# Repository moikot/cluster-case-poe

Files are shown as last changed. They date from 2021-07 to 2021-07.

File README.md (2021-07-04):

# A quiet case for three Raspberry Pis

* ✨Power over Ethernet
* ✨Hot-swap support 
* ✨PWM fans support
---

## Table of Contents

- [Enclosure](#enclosure)
  - [Power and I2C rail](#power-and-i2c-rail)
  - [Fan controller](#fan-controller)
  - [Bill of materials](#enclosure-bill-of-materials)
- [Frames](#frames)
  - [PoE assembly](#poe-assembly)
  - [Bill of materials](#frames-bill-of-materials)
- [Other hardware needed](#other-hardware-needed)
- [License](#license)

## Enclosure
<p align="center">
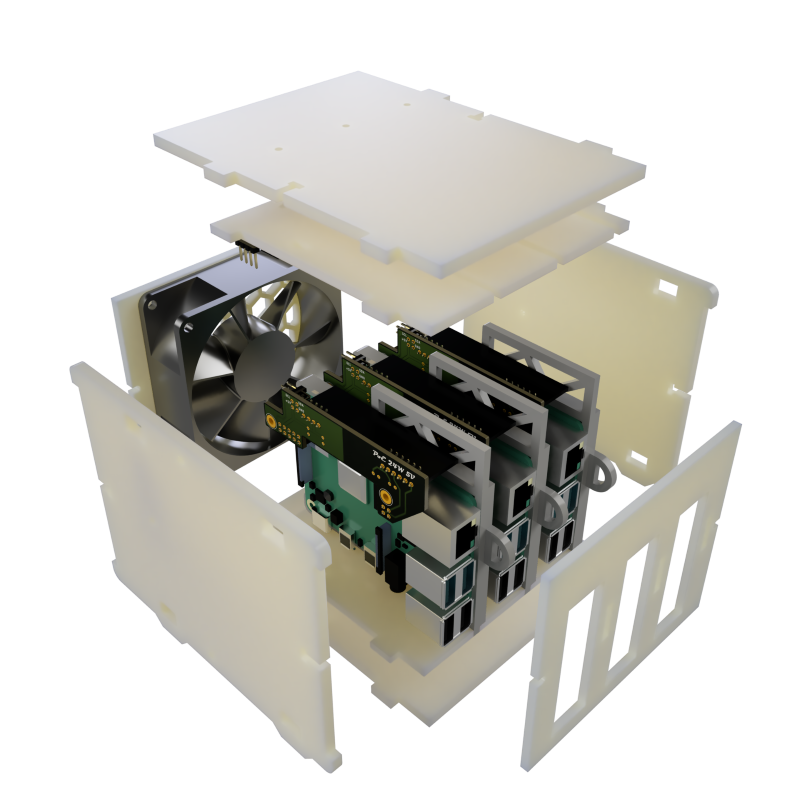
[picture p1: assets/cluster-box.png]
Enclosure

</p>

The case box is built from the following parts ([drawings](drawings/cluster-box-drawings.pdf)):

* Left, right, top, and bottom panels.
* Top and bottom panels with grooves for the Raspberry Pi frames.
* A back panel with a fan grill for 80mm x 80mm fan.
* A front panel with openings for USB and Ethernet ports. 

> Watch this [video](https://youtu.be/zfYN2NjLpm8) to see how to assembly the case.

### Power and I2C rail

The power and I2C rail connects all Raspberry Pis to the I2C bus and provides power to the fan controller and a chassis fan. Low forward drop Schottky diodes combined in an OR-ing circuit provide power to the load when at least one Raspberry Pi is installed without the risk of reverse current flow. 

<p align="center">
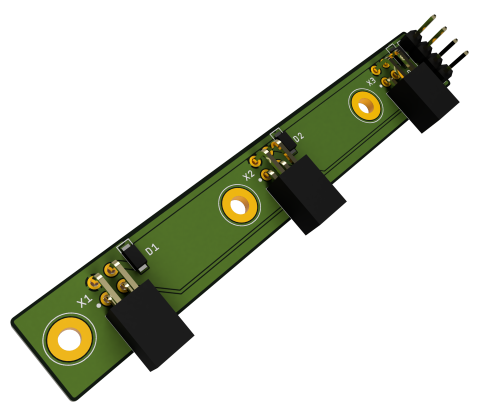
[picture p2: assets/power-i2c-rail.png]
Power I2C rail

</p>

> * [Schematics and PCB (EagleCAD)](power-rail)
> * [BOM](power-rail/power-rail-bom.csv)

### Fan controller

The fan controller converts 5V to 12V and uses [EMC2101-R IC](https://www.microchip.com/wwwproducts/en/EMC2101) from Microchip/SMSC to control a 4-pin PWM fan and monitor its speed via the I2C bus. This controller is installed on the left panel of the enclosure and connected to the [Power and I2C rail](#power-and-i2c-rail).

<p align="center">
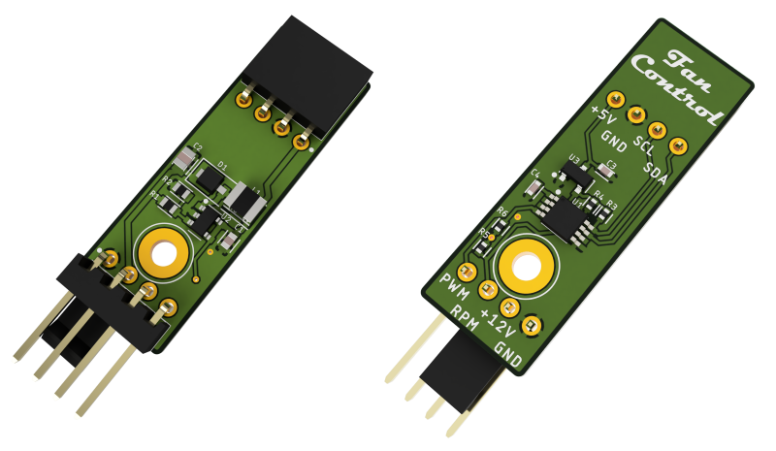
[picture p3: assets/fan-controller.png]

</p>

> * [Schematics and PCB (EagleCAD)](fan-controller)
> * [BOM](fan-controller/fan-controller-bom.csv)

### Bill of materials

| Part | Quantity | Link |
|---|---|---|
| M2.5 x 14mm screw | 3 | [M2.5 machine screws nuts kit](https://www.ebay.com/itm/182282169506) |
| M2.5 x 10mm screw | 1 | [M2.5 machine screws nuts kit](https://www.ebay.com/itm/182282169506) |
| M2.5 nut | 4 | [M2.5 machine screws nuts kit](https://www.ebay.com/itm/182282169506) |
| M2.5 x 2mm spacer | 4 | [M2.5 round plastic spacer](https://www.digikey.com/en/products/detail/w%C3%BCrth-elektronik/960020021/9488359) |
| M3 x 12mm screw | 8 | 	[M3x12mm machine screws](https://www.amazon.com/Uxcell-a15070200ux0058-Stainless-Phillips-Screws/dp/B012TE1TBS) |
| M3 nut | 8 | [M3 hexagon nuts](https://www.amazon.com/uxcell-Metric-Stainless-Hexagon-Silver/dp/B07H3T4859) |
| M3 nylon washer | 8 | [M3 nylon flat washers](https://www.amazon.com/uxcell-Insulation-Spacer-Washer-Gasket/dp/B016EPLM5G) |
| M4 x 14mm screw | 4 | [M4x14mm machine screws](https://www.amazon.com/uxcell-M4x14mm-Phillips-Stainless-Fasteners/dp/B07MF44LGC) |
| M4 nut | 4 | [M4 hexagon nuts](https://www.amazon.com/uxcell-Metric-Stainless-Hexagon-Silver/dp/B07H3VF3BF) |
| 80mm x 80mm x 25mm fan | 1 | [Noctua NF-A8 PWM](https://noctua.at/en/nf-a8-pwm) |
| Power and I2C rail | 1 | [Schematics and PCB (EagleCAD)](power-rail), [BOM](power-rail/power-rail-bom.csv) |
| Fan controller | 1 | [Schematics and PCB (EagleCAD)](fan-controller), [BOM](fan-controller/fan-controller-bom.csv) |
| Case panels | 8 | [Drawings](drawings/cluster-box-drawings.pdf), [Templates for laser cutting](drawings/cluster-box-laser-cut.pdf) |

## Frames

Raspberry Pis need to be mounted on frames so that they can be pushed into the case and retracted individually ([drawings](drawings/frame-drawings.pdf)).

<p align="center">
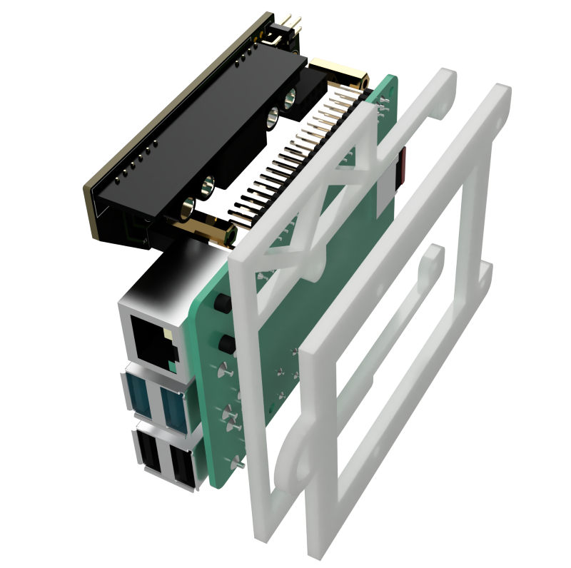
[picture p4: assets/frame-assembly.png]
Frame assembly

</p>

### PoE assembly

The solution relies on a custom PoE HAT with [RT5400-5V 30W module](https://www.aliexpress.com/item/33038562052.html). For this HAT to work, the switch your cluster is connected to needs to support IEEE 802.3af Power over Ethernet protocol (e.g. [TL-SG1005P switch](https://www.tp-link.com/us/business-networking/poe-switch/tl-sg1005p/)). 

<p align="center">
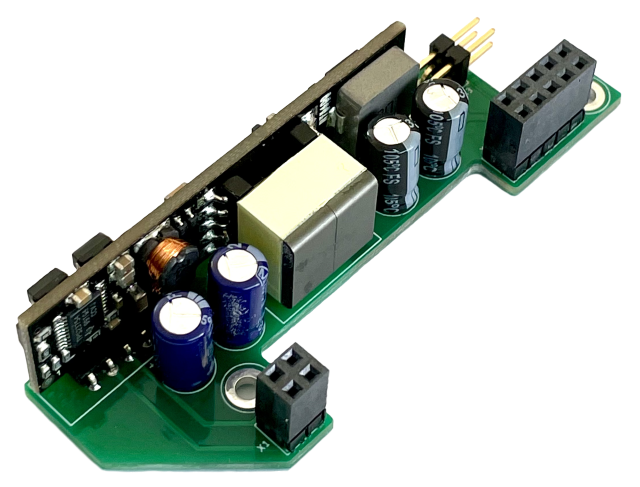
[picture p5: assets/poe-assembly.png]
Frame assembly

</p>

> * [Schematics and PCB (EagleCAD)](poe-assembly)
> * [BOM](poe-assembly/poe-assembly-bom.csv)

### Bill of materials
| Part | Quantity | Link |
|---|---|---|
| M2.5 x 10mm screw | 12 | [M2.5 machine screws nuts kit](https://www.ebay.com/itm/182282169506) |
| M2.5 x 5mm screw | 6 | [M2.5 machine screws nuts kit](https://www.ebay.com/itm/182282169506) |
| M2.5 nut | 6 | [M2.5 machine screws nuts kit](https://www.ebay.com/itm/182282169506) |
| M2.5 x 14mm F/F hex brass standoff | 6 | [Hex standoff M2.5 x 14mm brass](https://www.digikey.com/en/products/detail/harwin-inc/R25-1001402/3924434) |
| Raspberry Pi 4 Model B 4-8Gb | 3 | [Raspberry Pi 4](https://www.amazon.com/Uxcell-a15070200ux0058-Stainless-Phillips-Screws/dp/B012TE1TBS) | 
| Micro SD 32 Gb | 3 | [SanDisk Ultra 32GB](https://www.amazon.com/SanDisk-Ultra-UHS-I-Memory-Adapter/dp/B00M55C0NS) |
| PoE assembly | 3 | [Schematics and PCB (EagleCAD)](poe-assembly), [BOM](poe-assembly/poe-assembly-bom.csv) |
| Frame panels | 2 x 3 | [Drawings](drawings/frame-drawings.pdf), [Templates for laser cutting](drawings/frame-laser-cut.pdf) |

## Other hardware needed

* Three Ethernet patch cables 230-250mm length.
* A switch with 802.3af Power over Ethernet support (e.g. [TL-SG1005P switch](https://www.tp-link.com/us/business-networking/poe-switch/tl-sg1005p/)).

## License
This work is licensed under a Creative Commons Attribution-ShareAlike 4.0 International License, check [LICENSE](LICENSE) for more information.

You can support my work in the field of open-source hardware by clicking .

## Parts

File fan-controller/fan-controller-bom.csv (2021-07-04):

Designator | Name | Value | Amount | Case | Link
X1 | Connector | SSW-104-02-G-S-RA | 1 |  | https://no.mouser.com/ProductDetail/SSW-104-02-G-S-RA
X2 | Connector | KF2510-AW 3+1P | 1 |  | https://www.aliexpress.com/item/32961935772.html
C1 | Capacitor | 2.2uF 10V | 1 | 0603 | https://no.mouser.com/ProductDetail/187-CL10A225KP8NNNC
C2 | Capacitor | 10uF 16V | 1 | 0805 | https://no.mouser.com/ProductDetail/187-CL21A106KOQNNNE
C3,C4 | Capacitor | 0.1uF 10V | 2 | 0402_L | https://no.mouser.com/ProductDetail/187-CL05A104KP5NNWC
L1 | Inductor | 10uH | 1 | 1210 | https://no.mouser.com/ProductDetail/963-CBC3225T100KR
D1 | Schottky Diode |  | 1 | DO-216AA | https://no.mouser.com/ProductDetail/863-MBRM140T1G
R1 | Resistor | 43.2K | 1 | 0603 | https://no.mouser.com/ProductDetail/603-RC0603FR-0743K2L
R2 | Resistor | 4.99K | 1 | 0603 | https://no.mouser.com/ProductDetail/603-RC0603FR-074K99L
R3,R4,R6 | Resistor | 10K | 3 | 0402 | https://no.mouser.com/ProductDetail/603-RC0402FR-0710KL
R5 | Resistor | 5.6K | 1 | 0402 | https://no.mouser.com/ProductDetail/603-AC0402FR-075K6L
U1 | Voltage regulator | MIC2288YD5-TR | 1 | SOT-23-5 | https://no.mouser.com/ProductDetail/998-MIC2288YD5TR
U2 | Fan controller | EMC2101-R-ACZL-TR | 1 | MSOP-8 | https://no.mouser.com/ProductDetail/886-EMC2101RACZLTR
U3 | LDO 3.3V | AP7313-33SRG-7 | 1 | SOT-23-3 | https://no.mouser.com/ProductDetail/621-AP7313-33SRG-7

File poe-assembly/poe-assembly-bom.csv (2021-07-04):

Designator | Name | Value | Amount | Case | Link
X1 | Connector | ESQ-102-12-G-D | 1 |  | https://no.mouser.com/ProductDetail/200-ESQ10212GD
X2 | Connector | ESQ-105-12-G-D | 1 |  | https://no.mouser.com/ProductDetail/200-ESQ10512GD
X3 | Connector | TSW-102-08-G-D-RA | 1 |  | https://no.mouser.com/ProductDetail/TSW-102-08-G-D-RA
C1,C2 | Capacitor | 22uF 100V | 2 |  | https://no.mouser.com/ProductDetail/667-ECA-2AM220I
C3,C4 | Capacitor | 330uF 10V | 2 |  | https://no.mouser.com/ProductDetail/667-EEU-FS1A331
RT5400 | PoE module | RT5400 5V | 1 |  | https://www.aliexpress.com/item/33038562052.html

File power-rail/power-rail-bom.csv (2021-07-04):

Designator | Name | Value | Amount | Case | Link
X1,X2,X3 | Connector | SSW-102-02-G-D-RA | 3 |  | https://no.mouser.com/ProductDetail/SSW-102-02-G-D-RA
X4 | Connector | TSW-104-07-F-S | 1 |  | https://no.mouser.com/ProductDetail/200-TSW10407FS
D1,D2,D2 | Schottky Diode | RB161MM-20TR | 3 |  | https://no.mouser.com/ProductDetail/755-RB161MM-20TR

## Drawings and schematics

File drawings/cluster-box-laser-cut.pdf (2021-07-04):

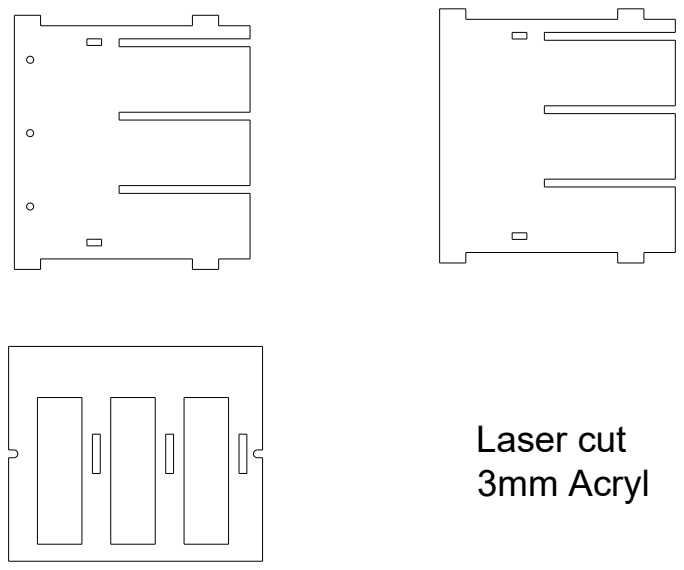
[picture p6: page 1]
Laser cut 3mm Acryl

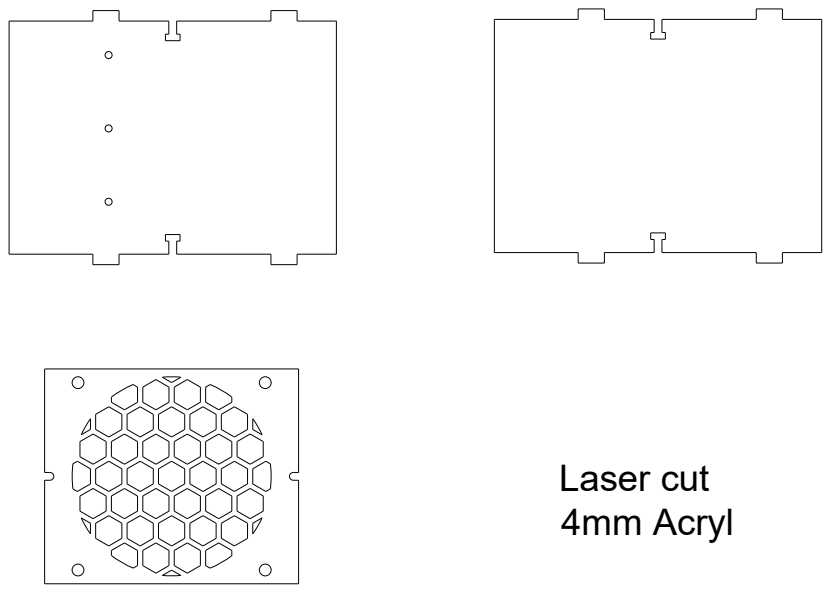
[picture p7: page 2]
Laser cut 4mm Acryl

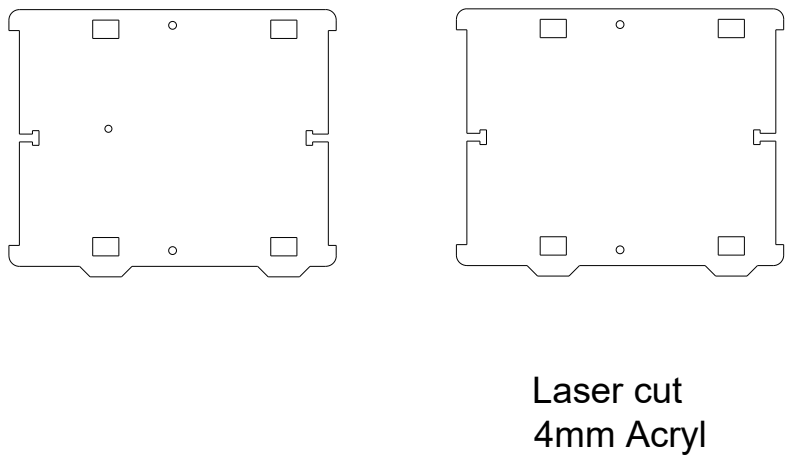
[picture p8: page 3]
Laser cut 4mm Acryl

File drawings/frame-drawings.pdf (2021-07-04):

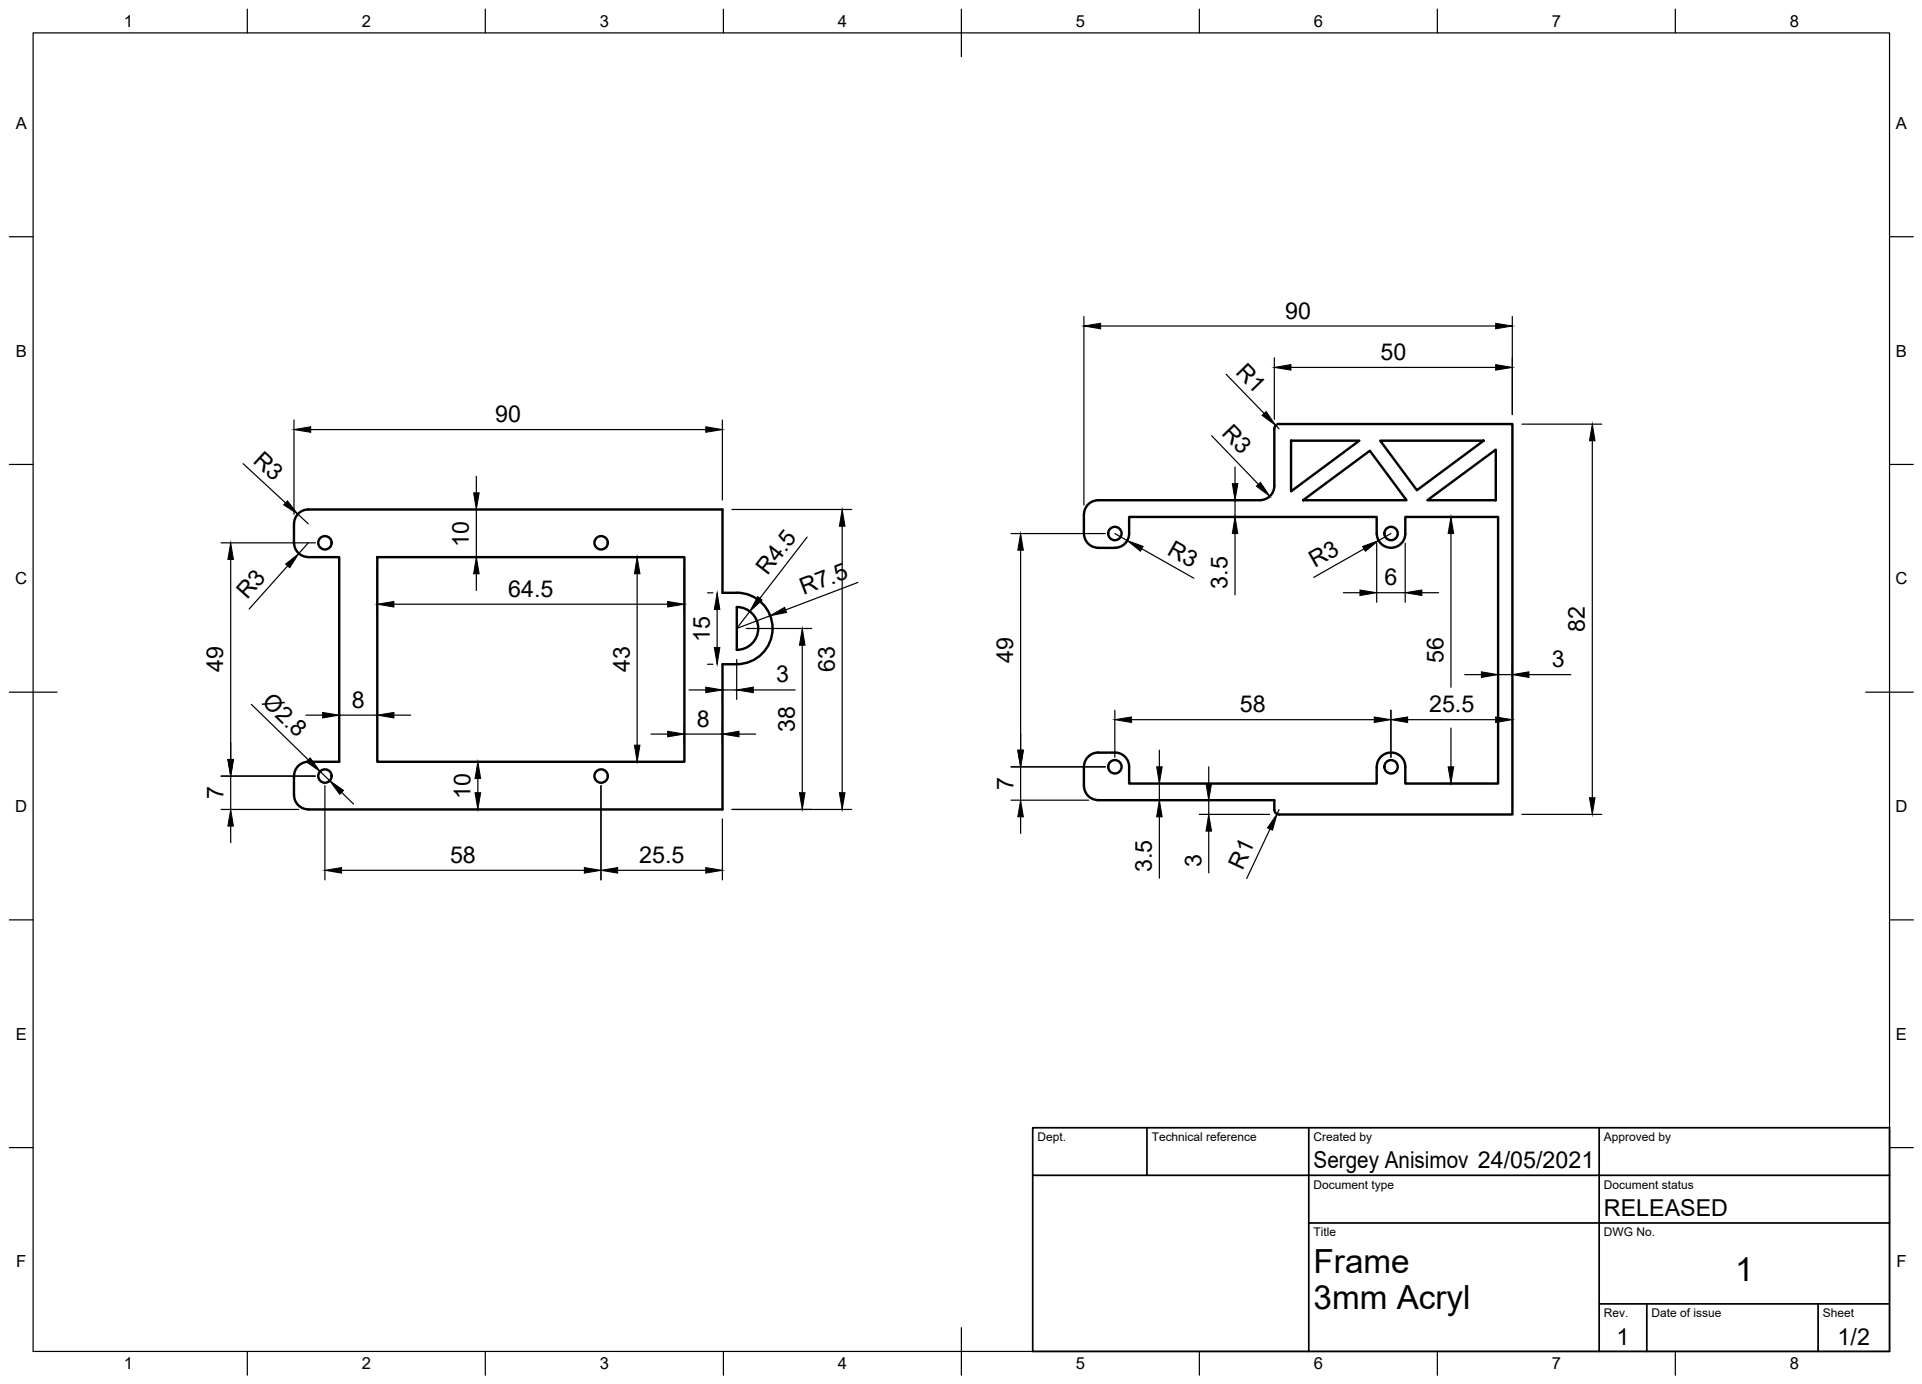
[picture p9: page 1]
Title; DWG No.; Rev.; Date of issue; Sheet; 3mm Acryl

Dept. | Technical reference | Created by Sergey Anisimov 24/05/2021 | Approved by

Document type | Document status RELEASED

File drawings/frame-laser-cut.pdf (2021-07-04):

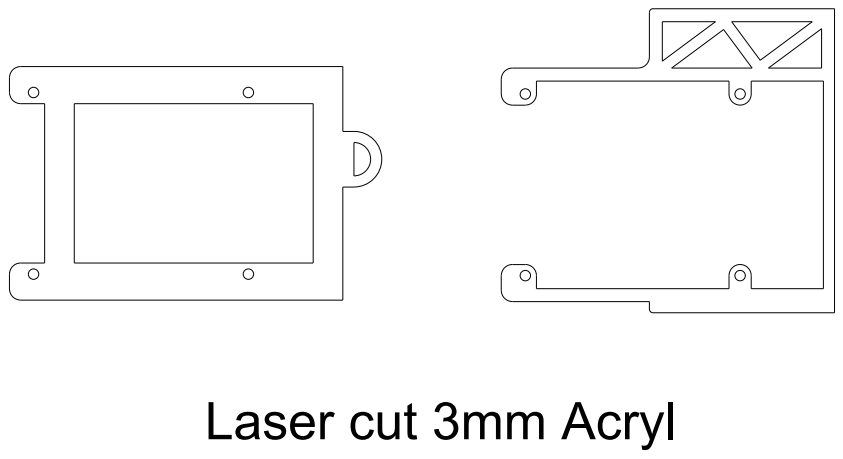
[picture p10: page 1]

Laser cut 3mm Acryl

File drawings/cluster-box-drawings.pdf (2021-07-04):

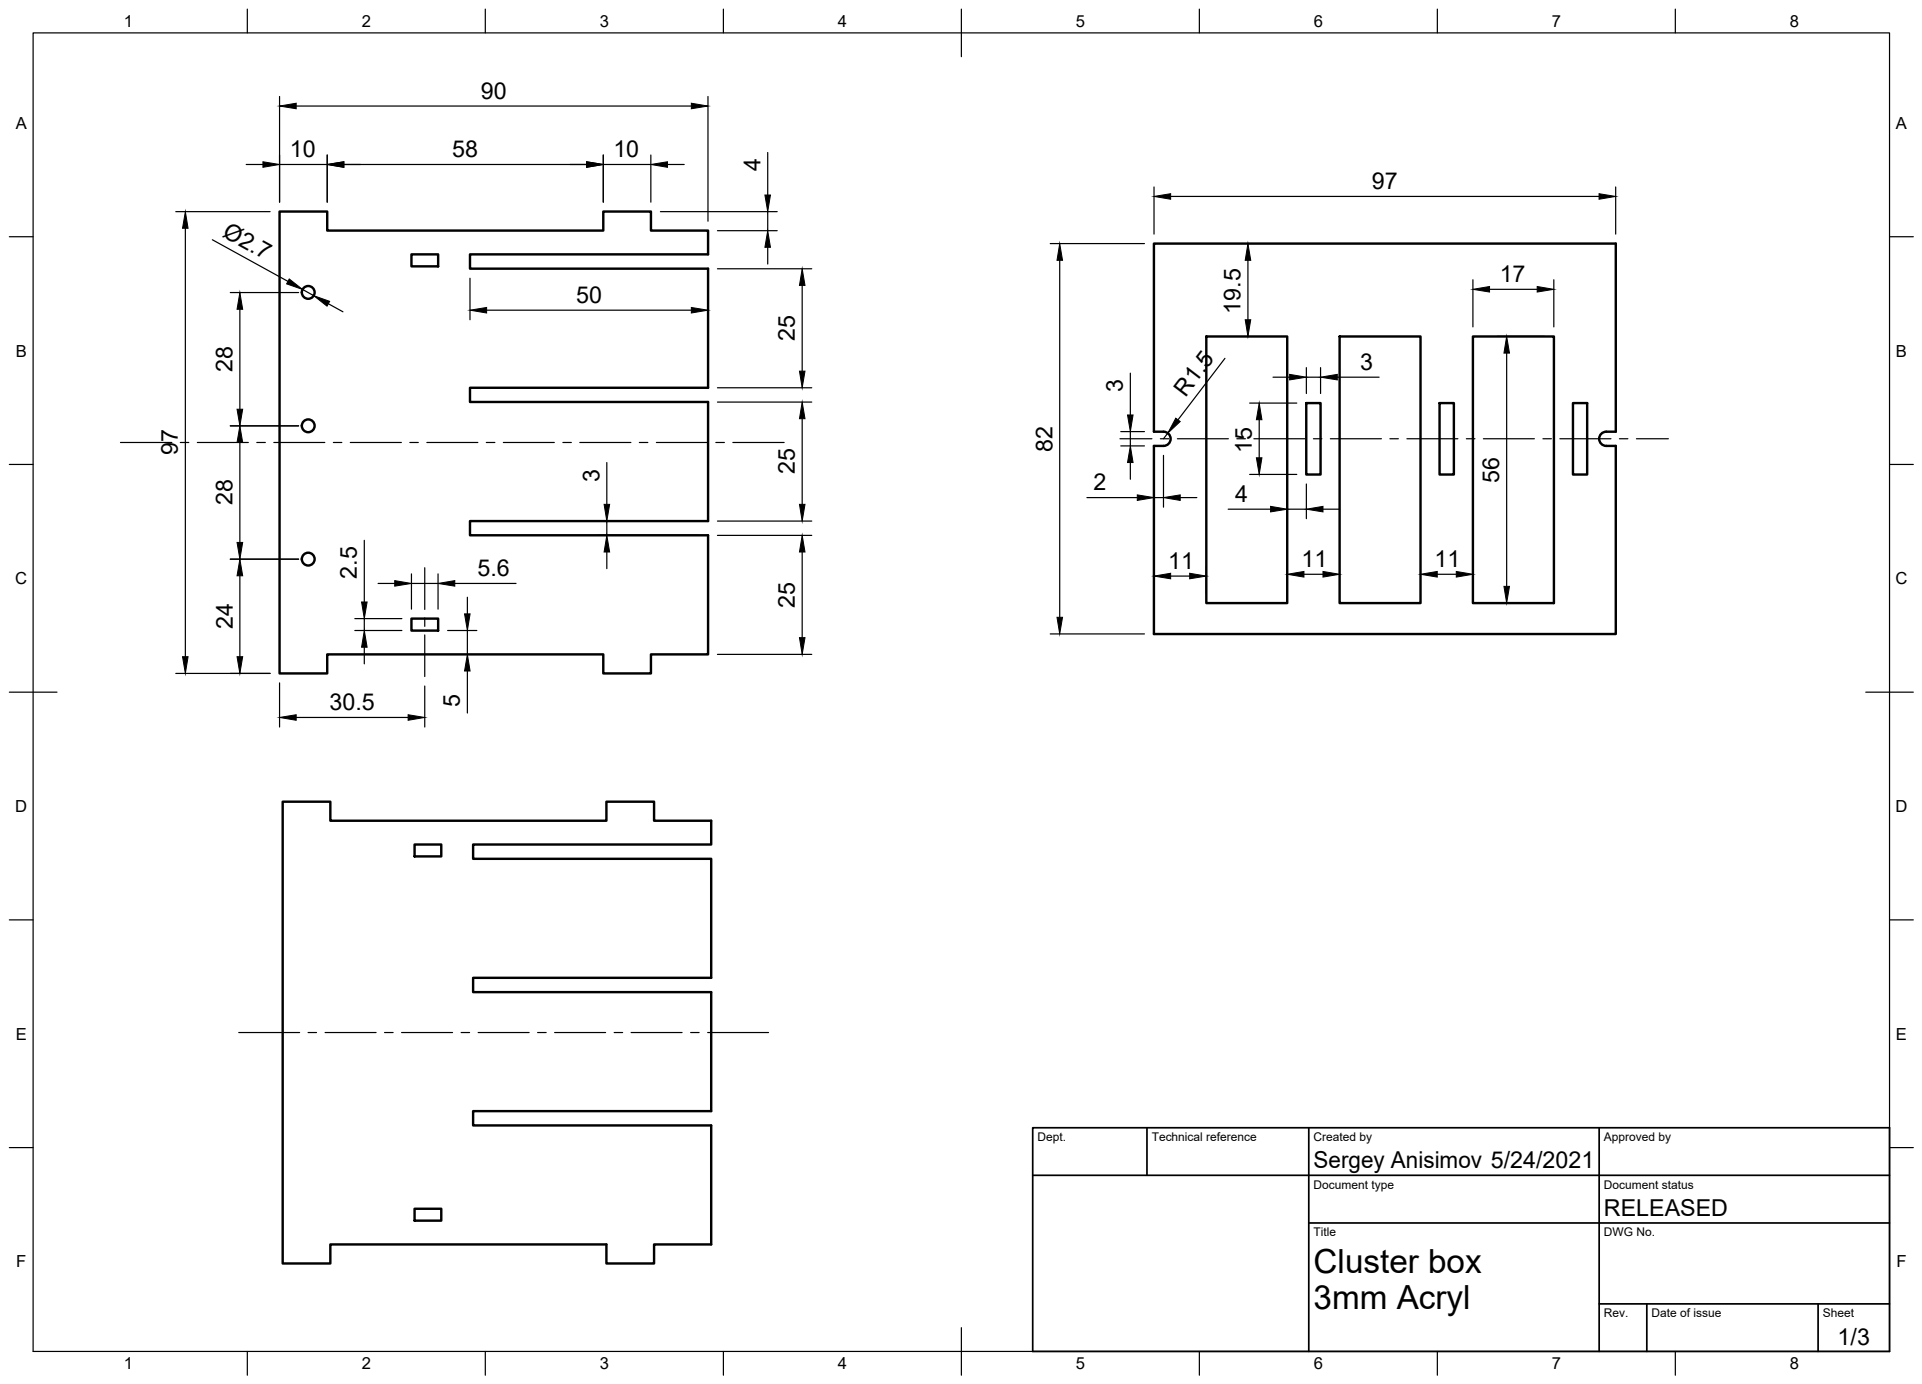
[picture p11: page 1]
Title; DWG No.; Rev.; Date of issue; Sheet; 3mm Acryl; Cluster box

Dept. | Technical reference | Created by Sergey Anisimov 5/24/2021 | Approved by

Document type | Document status RELEASED

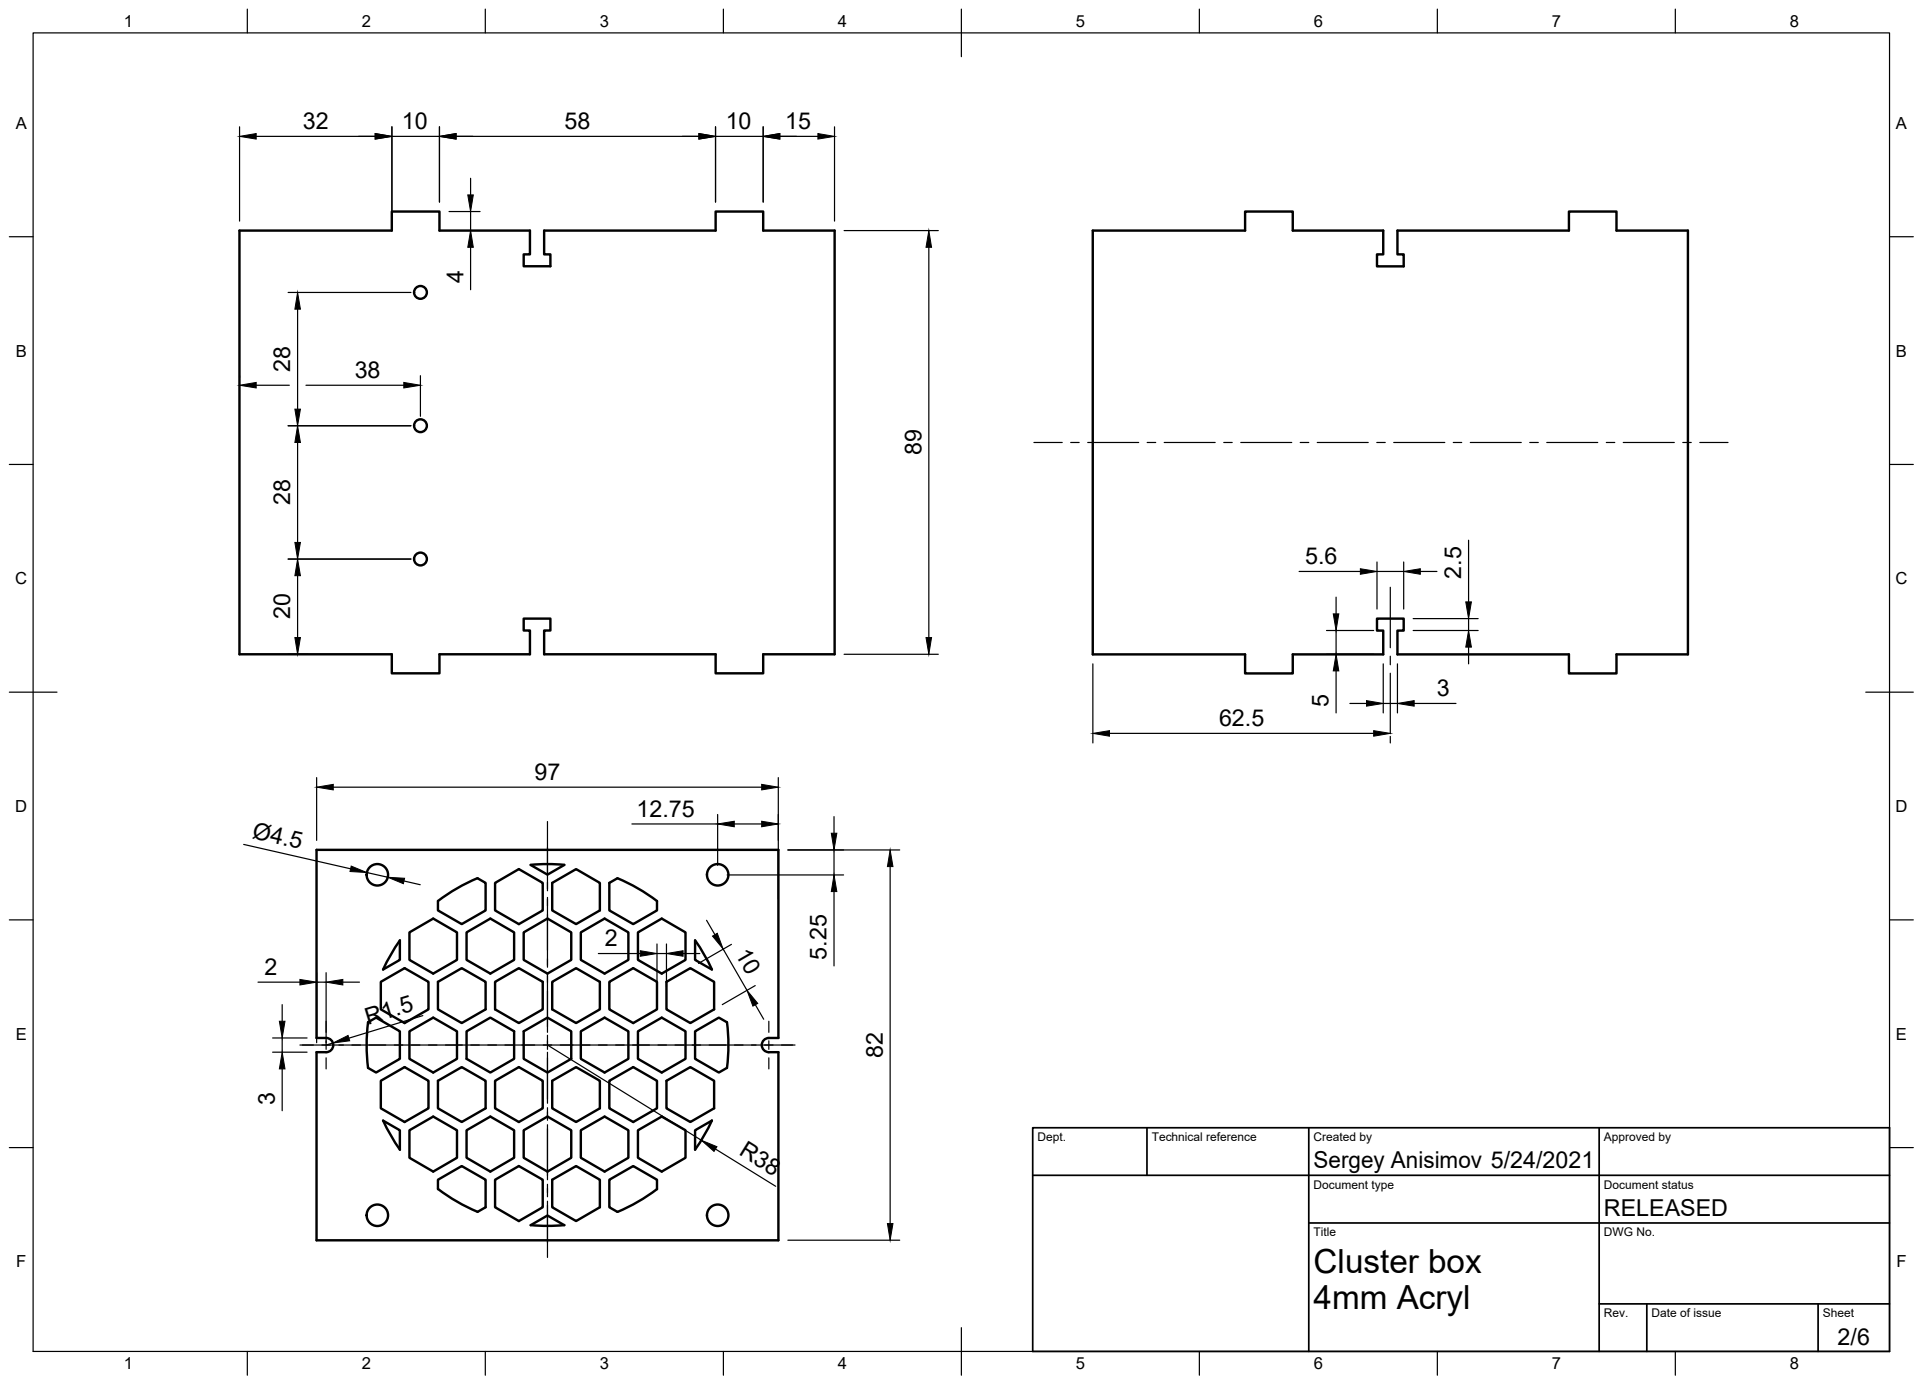
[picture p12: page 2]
Title; DWG No.; Cluster box

Dept. | Technical reference | Created by Sergey Anisimov 5/24/2021 | Approved by

Document type | Document status RELEASED

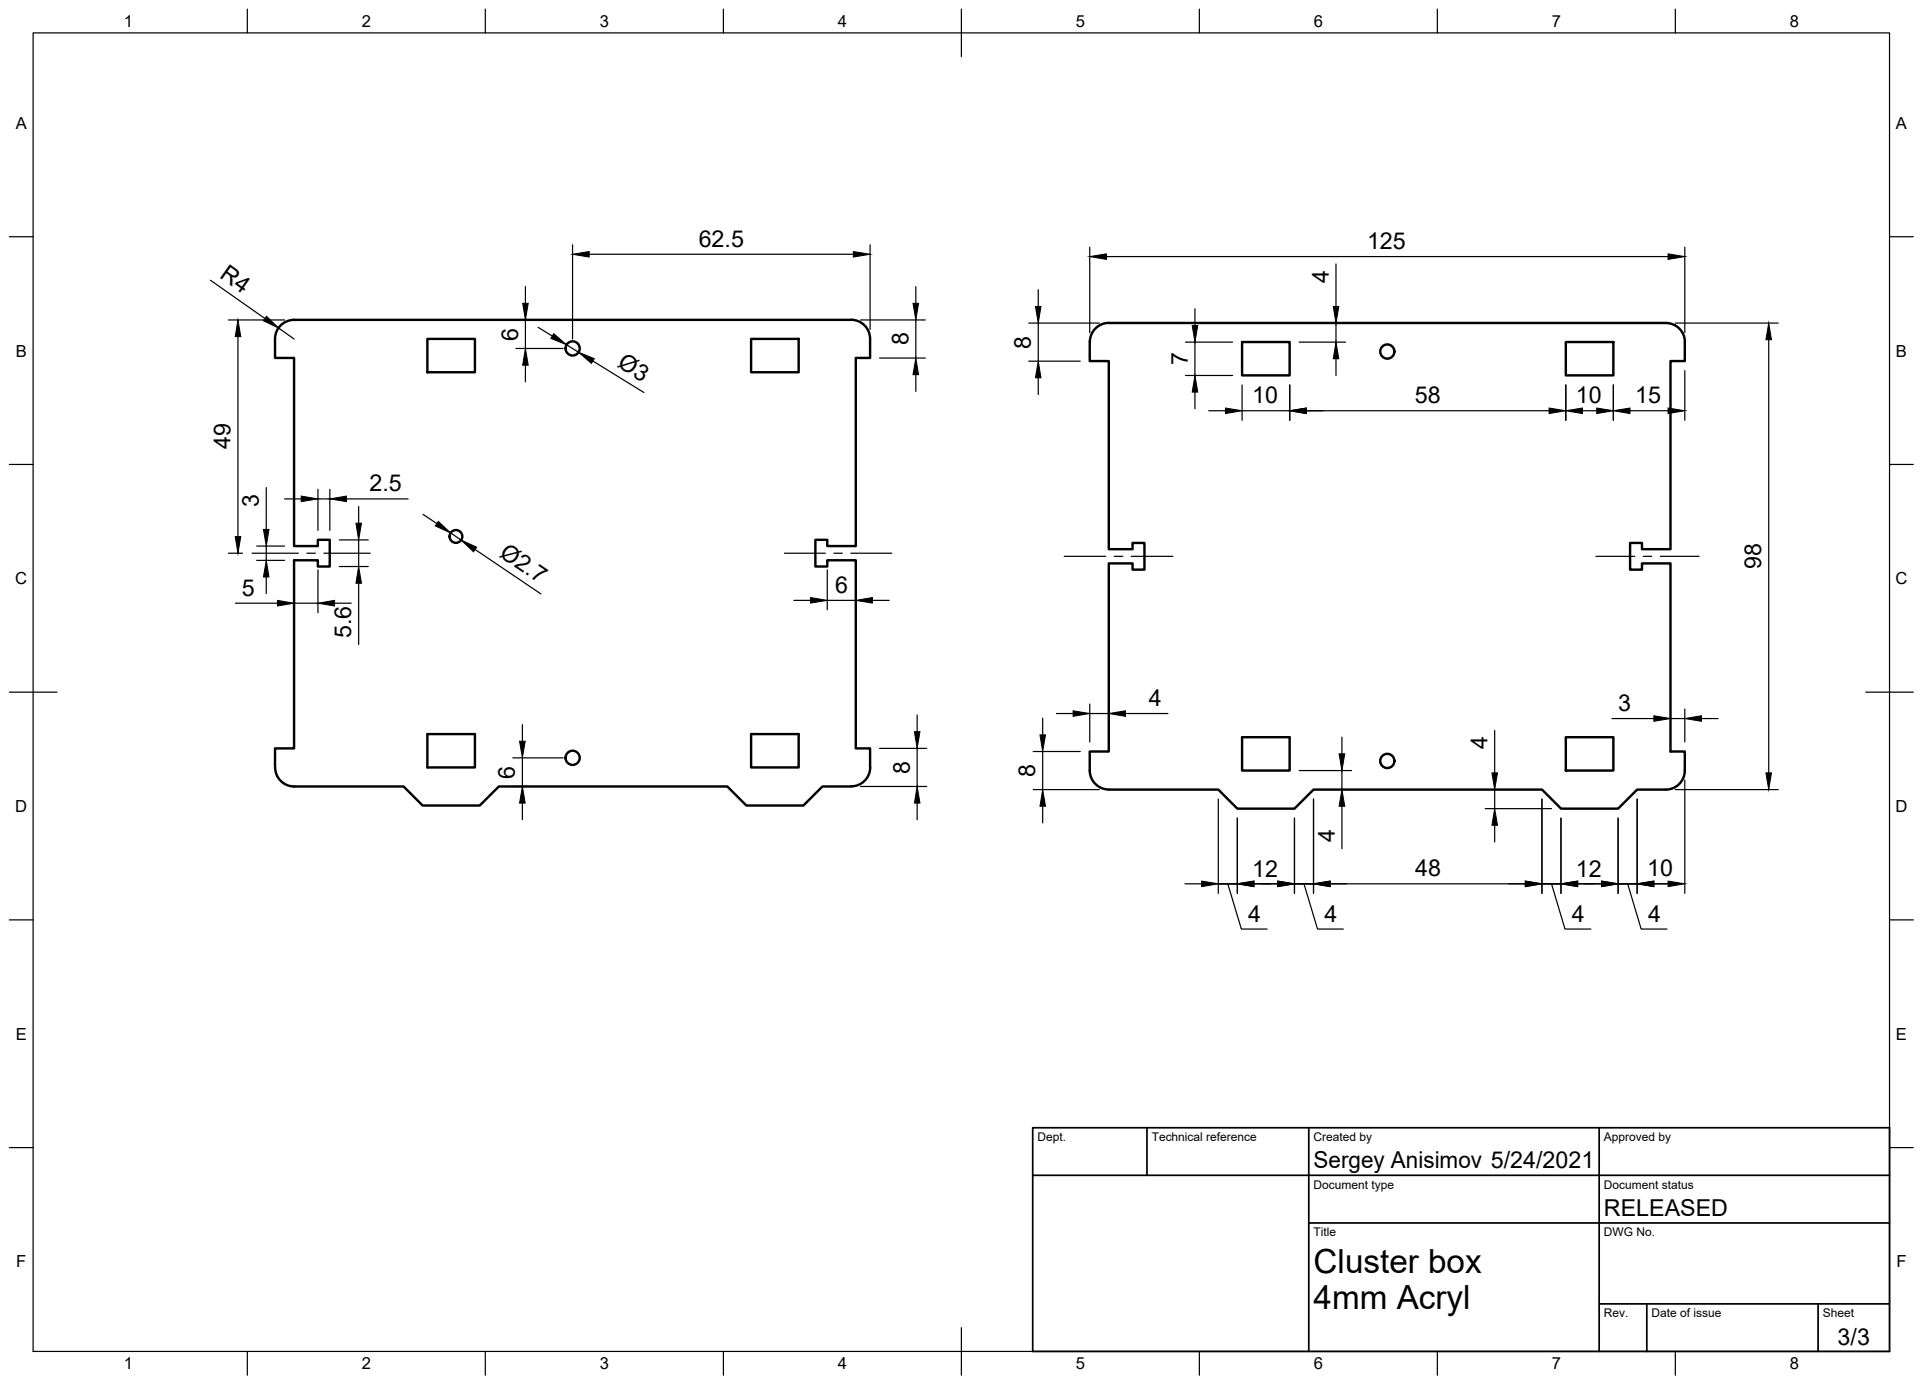
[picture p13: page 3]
Title; DWG No.; Cluster box

Dept. | Technical reference | Created by Sergey Anisimov 5/24/2021 | Approved by

Document type | Document status RELEASED

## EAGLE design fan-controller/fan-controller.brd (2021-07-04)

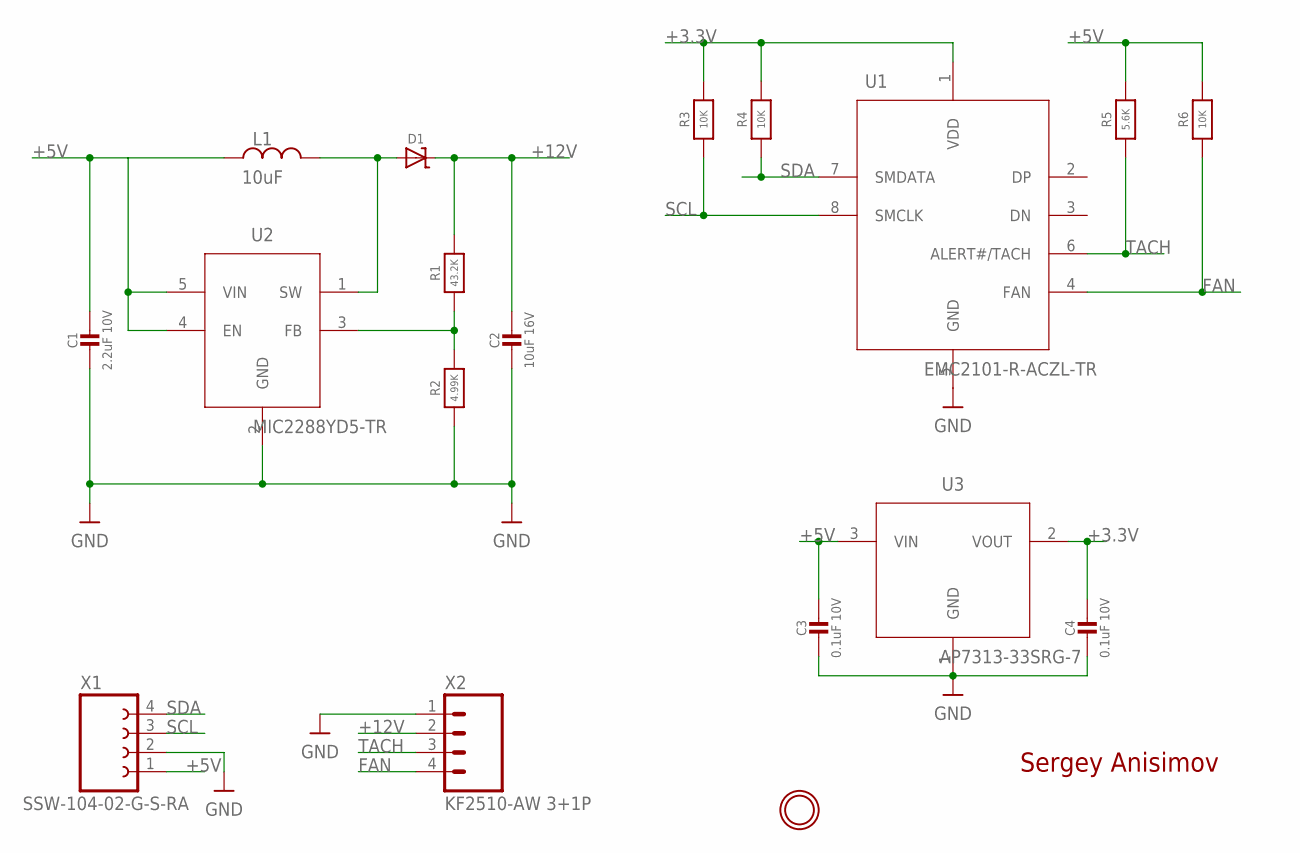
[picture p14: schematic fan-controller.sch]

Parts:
C1: 2.2uF 10V; CAPC1608X50N
C2: 10uF 16V; CAPC2012X139N
C3, C4: 0.1uF 10V; CAPC1205X55N
D1: DIODE-SCHOTTKY; CASE457−04
L1: 10uF; INDC3225X270
R1: 43.2K; RESC1608X55N
R2: 4.99K; RESC1608X55N
R3, R4, R6: 10K; RESC1005X40N
R5: 5.6K; RESC1005X40N
U1: EMC2101-R-ACZL-TR; SOP65P490X110-8N
U2: MIC2288YD5-TR; SOT95P279X100-5
U3: AP7313-33SRG-7; SOT95P240X120-3
U$7: MOUNTING-HOLE2.7_THICK; MOUNTINGHOLE_2.7_PLATED_THICK
X1: SSW-104-02-G-S-RA; HDRRAR4W64P254_1X4_1067X851X241B
X2: KF2510-AW 3+1P; HDRRA4W64P254_1X4_1016X300X580B

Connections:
+3.3V: C4.1, R3.2, R4.2, U1.1 (VDD), U3.2 (VOUT)
+5V: C1.1, C3.1, L1.1, R5.2, R6.2, U2.4 (EN), U2.5 (VIN), U3.3 (VIN), X1.1
+12V: C2.1, D1.C, R1.1, X2.2
FAN: R6.1, U1.4 (FAN), X2.4
GND: C1.2, C2.2, C3.2, C4.2, R2.1, U1.5 (GND), U2.2 (GND), U3.1 (GND), X1.2, X2.1
unnamed: D1.A, L1.2, U2.1 (SW)
unnamed: R1.2, R2.2, U2.3 (FB)
SCL: R3.1, U1.8 (SMCLK), X1.3
SDA: R4.1, U1.7 (SMDATA), X1.4
TACH: R5.1, U1.6 (ALERT#/TACH), X2.3

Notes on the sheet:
Sergey Anisimov

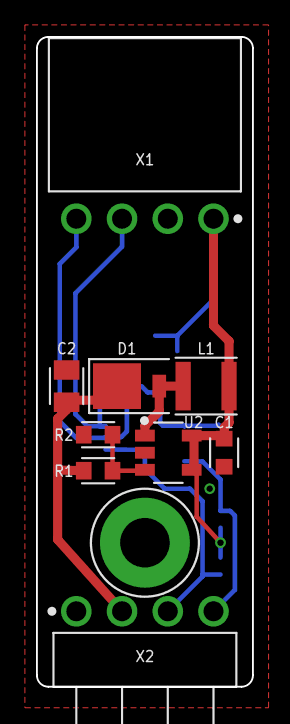
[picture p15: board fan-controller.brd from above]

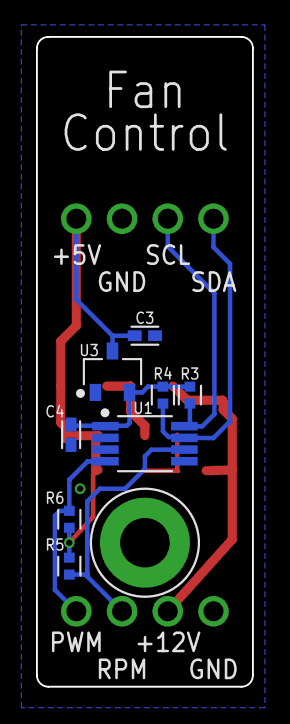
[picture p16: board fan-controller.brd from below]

Board: 2 copper layers, 12.0 x 36.1 mm, 18 parts (8 on the bottom side), 10 nets.

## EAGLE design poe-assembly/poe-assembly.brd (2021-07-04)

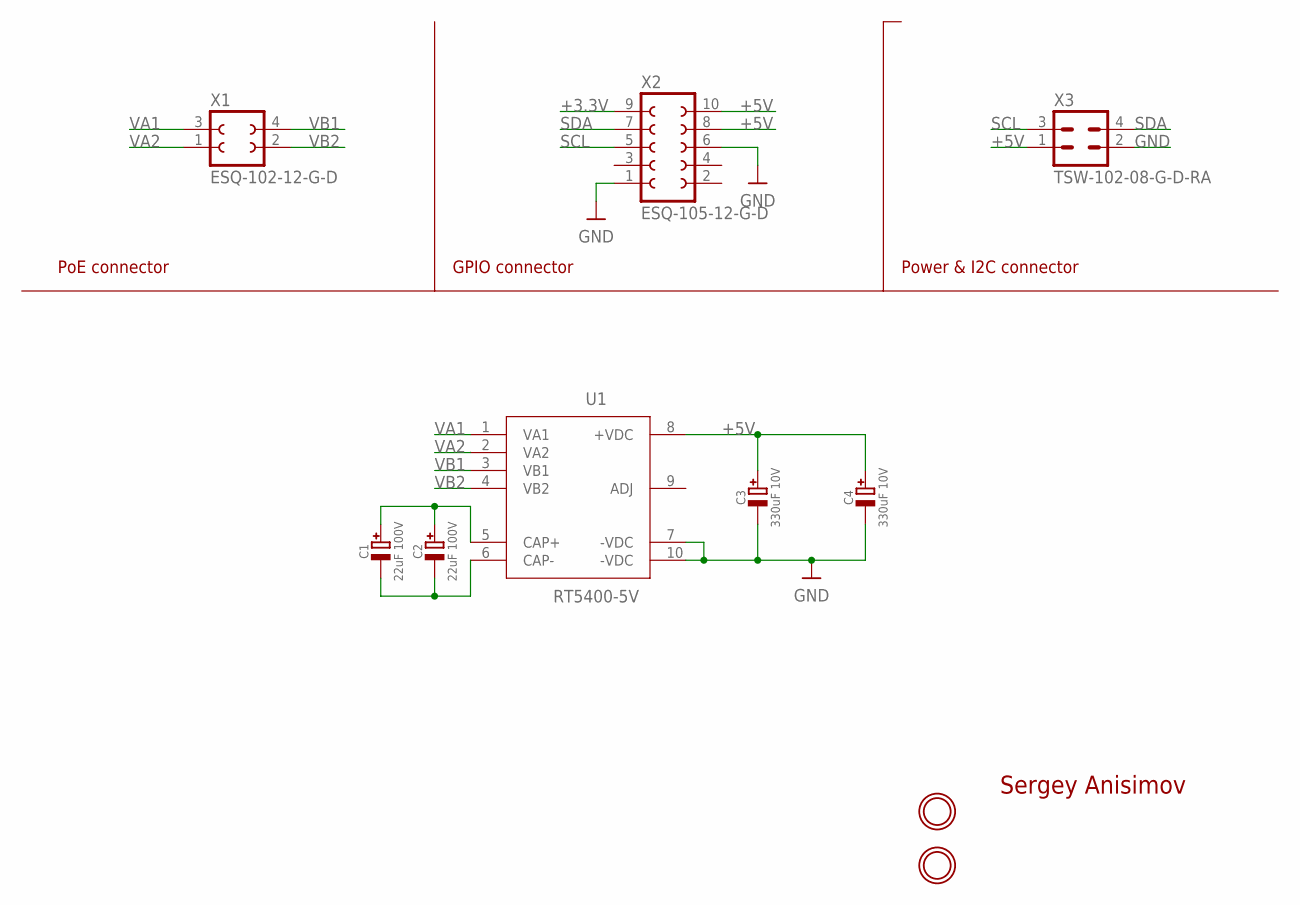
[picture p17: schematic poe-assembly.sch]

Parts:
C1, C2: 22uF 100V; CAP-PRD250-W50-D630
C3, C4: 330uF 10V; CAP-PRD250-W50-D630
U1: RT5400-5V; MODULE-RT5400
U$6, U$7: MOUNTING-HOLE2.7_THICK; MOUNTINGHOLE_2.7_PLATED_THICK
X1: ESQ-102-12-G-D; ESQ-102-D
X2: ESQ-105-12-G-D; ESQ-105-D
X3: TSW-102-08-G-D-RA; TSW-102-D-RA

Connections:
+3.3V: X2.9
+5V: C3.1 (+), C4.1 (+), U1.8 (+VDC), X2.8, X2.10, X3.1
GND: C3.2 (-), C4.2 (-), U1.7 (-VDC), U1.10 (-VDC), X2.1, X2.6, X3.2
unnamed: C1.1 (+), C2.1 (+), U1.5 (CAP+)
unnamed: C1.2 (-), C2.2 (-), U1.6 (CAP-)
SCL: X2.5, X3.3
SDA: X2.7, X3.4
VA1: U1.1 (VA1), X1.3
VA2: U1.2 (VA2), X1.1
VB1: U1.3 (VB1), X1.4
VB2: U1.4 (VB2), X1.2

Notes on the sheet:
Sergey Anisimov
PoE connector
GPIO connector
Power & I2C connector

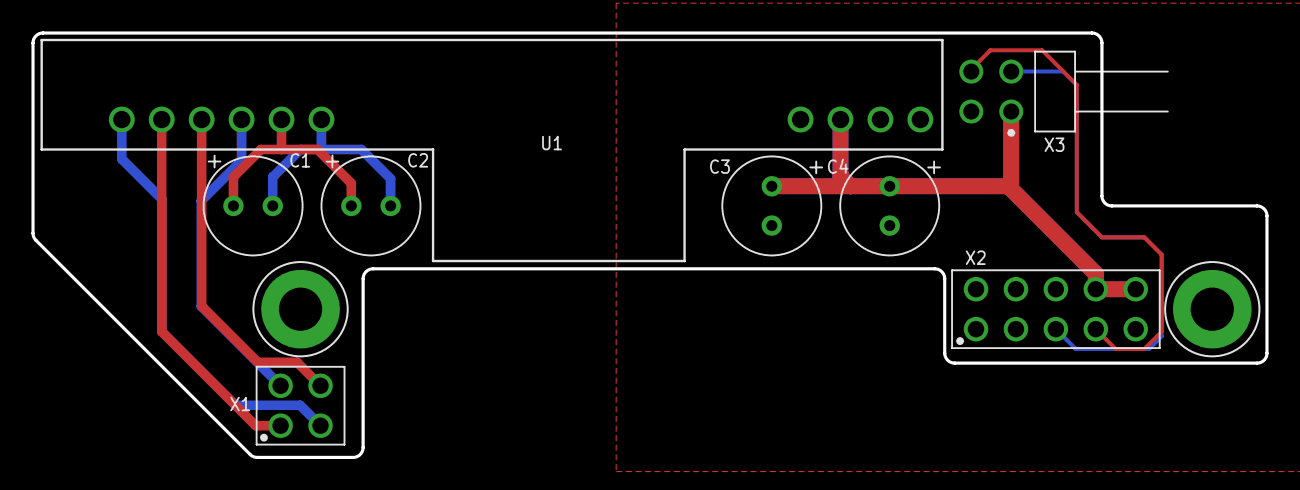
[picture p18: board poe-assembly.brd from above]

Board: 2 copper layers, 78.5 x 27.0 mm, 10 parts (0 on the bottom side), 10 nets.

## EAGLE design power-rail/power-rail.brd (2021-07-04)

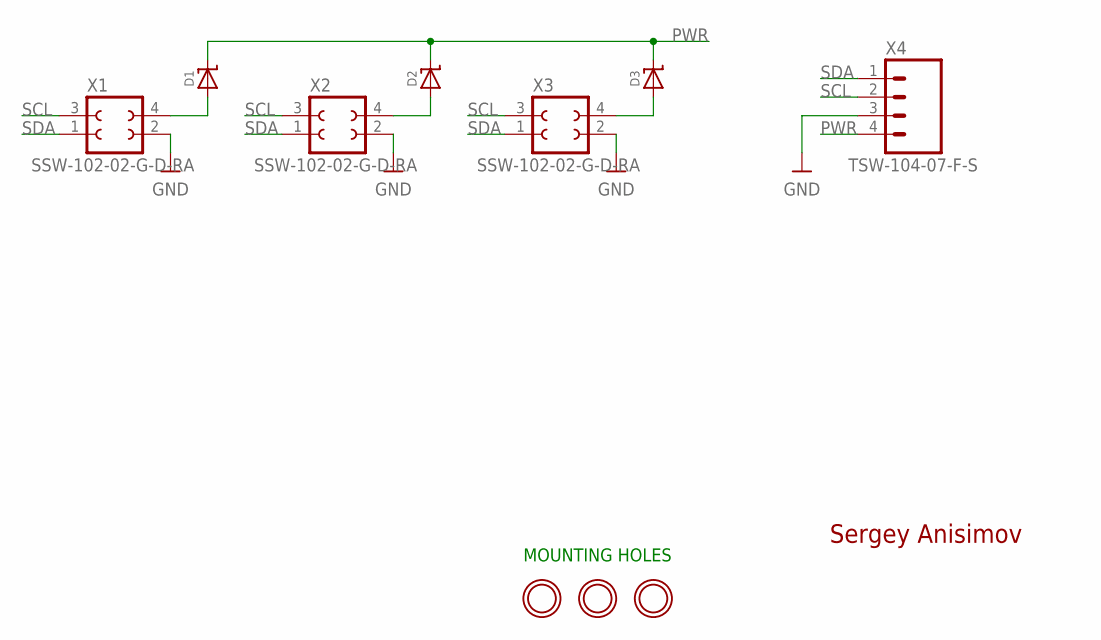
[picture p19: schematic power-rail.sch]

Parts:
D1, D2, D3: DIODE-SCHOTTKYSOD−123FL; SODFL3616X98
U$5, U$6, U$7: MOUNTING-HOLE2.7_THICK; MOUNTINGHOLE_2.7_PLATED_THICK
X1, X2, X3: SSW-102-02-G-D-RA; SSQ-102-02-T-D-RA
X4: TSW-104-07-F-S; HDRV4W64P254_1X4_1016X254X838B

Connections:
GND: X1.2, X2.2, X3.2, X4.3
unnamed: D1.A, X1.4
unnamed: D2.A, X2.4
unnamed: D3.A, X3.4
PWR: D1.C, D2.C, D3.C, X4.4
SCL: X1.3, X2.3, X3.3, X4.2
SDA: X1.1, X2.1, X3.1, X4.1

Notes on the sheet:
MOUNTING HOLES
Sergey Anisimov

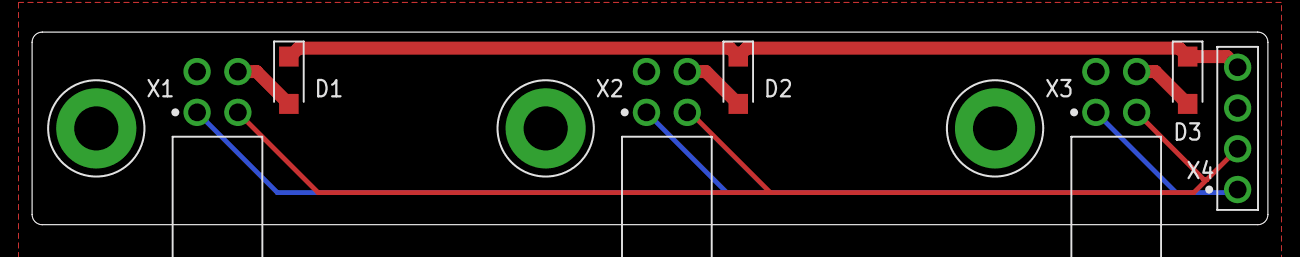
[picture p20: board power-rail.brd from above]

Board: 2 copper layers, 77.0 x 12.0 mm, 10 parts (0 on the bottom side), 7 nets.
